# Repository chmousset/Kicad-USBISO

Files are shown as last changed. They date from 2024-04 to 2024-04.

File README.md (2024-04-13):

# USB Isolator

The title says it all: it isolates an USB port.

It will be useful to break ground loops, or to protect your laptop when working on high voltage devices such as an AC motor controller.
Commercially-available offerings either lacked proper isolation for working with mains voltage (only 1kV isolation rating), full USB 2.0 speed (limited to 12Mbps), partial USB3.0 support, or a high price point (onwards to 1000€ range).

The ADUM1366 is the main chip that isolates USB2.0 LS, FS and HS (1.5, 12 and 480Mbps respectively). It's tested at 3750V for 1 minute.
5V @1A of output power is provided through the onboard REC5A DC/DC converter, which is tested at 2kV for 1 min. If higher insulation is required, other DC/DC converters with similar package and 3 kV or more rating exist.

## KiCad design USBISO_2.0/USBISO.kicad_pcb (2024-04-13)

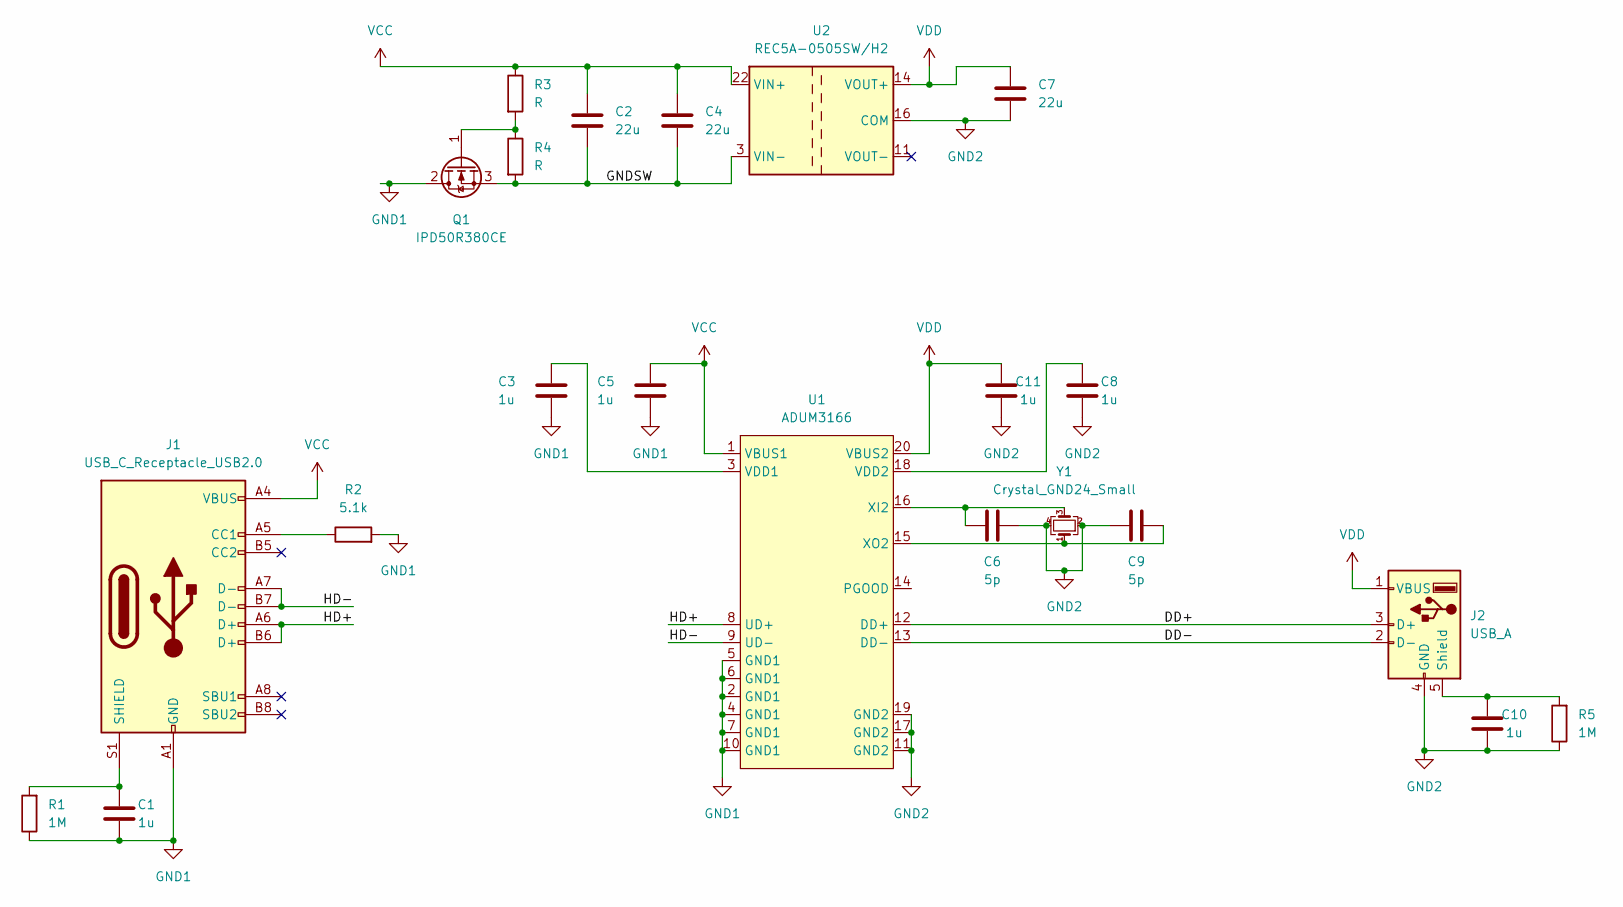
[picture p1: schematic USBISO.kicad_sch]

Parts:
C1, C3, C5, C8, C10, C11: 1u; C_0805_2012Metric
C2, C4, C7: 22u; C_1210_3225Metric
C6, C9: 5p; C_0603_1608Metric
J1: USB_C_Receptacle_USB2.0; USB_C_Receptacle_GCT_USB4085
J2: USB_A; USB_A_CONNFLY_DS1095-WNR0
Q1: IPD50R380CE; TO-252-2
R1, R5: 1M; R_0603_1608Metric
R2: 5.1k; R_0603_1608Metric
R3, R4: R; R_0603_1608Metric
U1: ADUM3166; SSOP-20_5.3x7.2mm_P0.65mm
U2: REC5A-0505SW/H2; Converter_DCDC_XP_POWER_JTExxxxDxx_THT
Y1: Crystal_GND24_Small; Crystal_SMD_3225-4Pin_3.2x2.5mm

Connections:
/DD+: J2.3 (D+), U1.12 (DD+)
/DD-: J2.2 (D-), U1.13 (DD-)
/GNDSW: C2.2, C4.2, Q1.3 (S), R4.2, U2.2 (VIN-), U2.3 (VIN-)
/HD+: J1.A6 (D+), J1.B6 (D+), U1.8 (UD+)
/HD-: J1.A7 (D-), J1.B7 (D-), U1.9 (UD-)
GND1: C1.1, C3.2, C5.2, J1.A1 (GND), J1.A12 (GND), J1.B1 (GND), J1.B12 (GND), Q1.2 (D), R1.1, R2.2, U1.2 (GND1), U1.4 (GND1), U1.5 (GND1), U1.6 (GND1), U1.7 (GND1), U1.10 (GND1)
GND2: C6.2, C7.2, C8.1, C9.1, C10.1, C11.1, J2.4 (GND), R5.1, U1.11 (GND2), U1.17 (GND2), U1.19 (GND2), U2.9 (COM), U2.16 (COM), Y1.2, Y1.4
unnamed: C1.2, J1.S1 (SHIELD), R1.2
unnamed: C3.1, U1.3 (VDD1)
unnamed: C6.1, U1.16 (XI2), Y1.3
unnamed: C8.2, U1.18 (VDD2)
unnamed: C9.2, U1.15 (XO2), Y1.1
unnamed: C10.2, J2.5 (Shield), R5.2
unnamed: J1.A5 (CC1), R2.1
unnamed: Q1.1 (G), R3.2, R4.1
VCC: C2.1, C4.1, C5.1, J1.A4 (VBUS), J1.A9 (VBUS), J1.B4 (VBUS), J1.B9 (VBUS), R3.1, U1.1 (VBUS1), U2.22 (VIN+), U2.23 (VIN+)
VDD: C7.1, C11.2, J2.1 (VBUS), U1.20 (VBUS2), U2.14 (VOUT+)

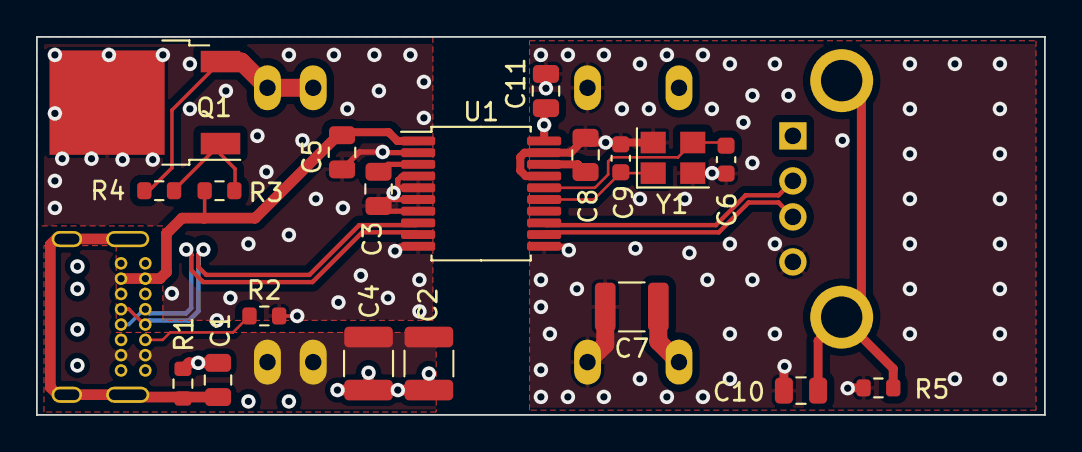
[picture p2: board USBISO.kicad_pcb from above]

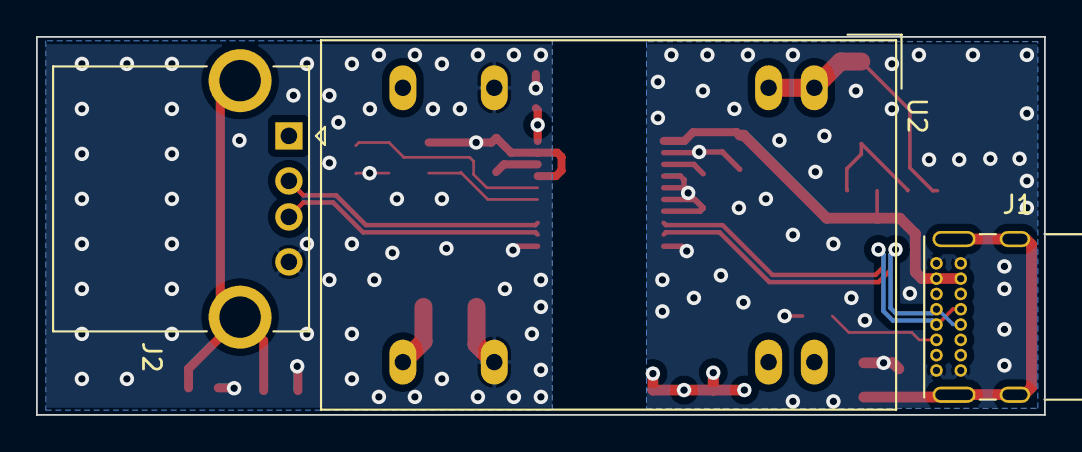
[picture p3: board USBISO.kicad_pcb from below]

Board: 4 copper layers, 56.0 x 21.0 mm, 22 parts (3 on the bottom side), 17 nets.
